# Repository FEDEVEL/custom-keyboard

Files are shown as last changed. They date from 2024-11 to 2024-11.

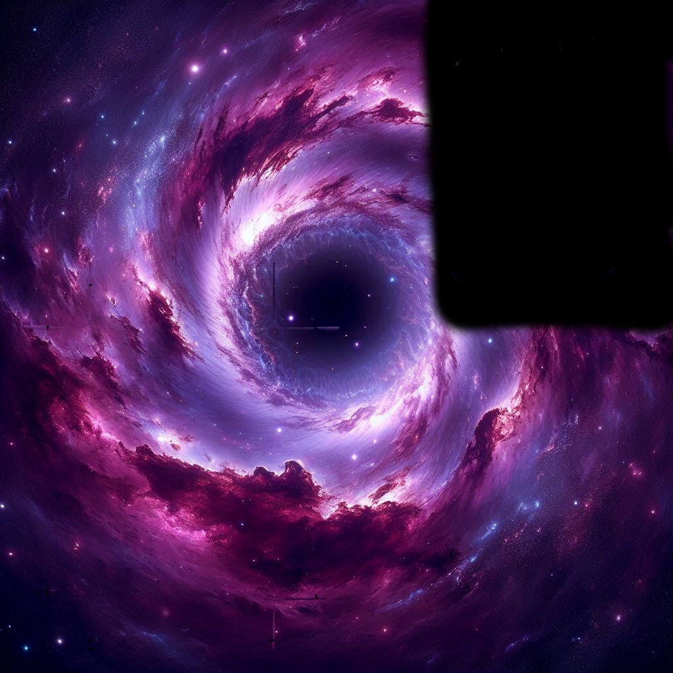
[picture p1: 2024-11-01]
Hardware/Manufacturing/Top and Bottom Box - Multicolor/bttex.png

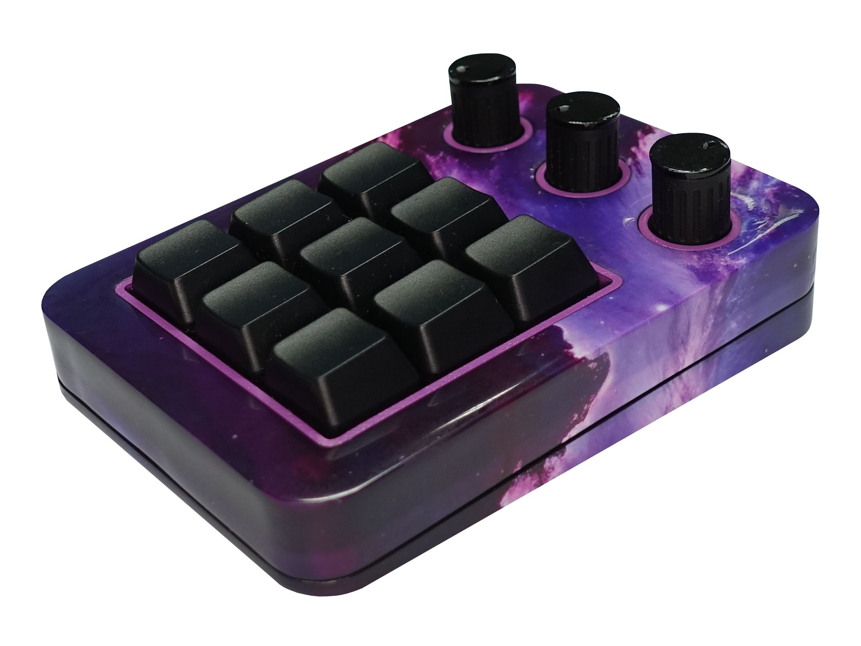
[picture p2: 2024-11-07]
Assets/keyboard.jpg

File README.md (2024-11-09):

# Custom keyboard
To design this keyboard by yourself watch my full step-by-step tutorial here: https://www.youtube.com/playlist?list=PLXvLToQzgzdftro2qK5In8p6ExsDFdpzw

Custom Keyboard Tutorial (https://www.youtube.com/watch?v=N4cLFE0FF2U)

## What is here
You will find here all the files needed to build the custom keyboard from my video tutorial.

## Other
### Have a look at the schematic and PCB layout
You can open schematic and PCB directly here: https://oshwlab.com/robertferanec/custom-keyboard
### See the 3D files
You can download 3D files also from my thingiverse here: https://www.thingiverse.com/thing:6784228 

# License
Custom Keyboard © 2025 by FEDEVEL is licensed under [Creative Commons Attribution-NonCommercial-ShareAlike 4.0 International](https://creativecommons.org/licenses/by-nc-sa/4.0/?ref=chooser-v1). For commercial use, contact me at info@fedevel.com

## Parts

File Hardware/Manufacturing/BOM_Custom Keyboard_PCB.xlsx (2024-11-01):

No. | Quantity | Comment | Designator | Footprint | Value | Manufacturer Part | Manufacturer | Supplier Part | Supplier | Layer
1 | 7 | 2.2uF | C101,C105,C106,C107,C201,C202,C207 | C0402 | 2.2uF | CL05A225MQ5NSNC | SAMSUNG(三星) | C12530 | LCSC | B
2 | 21 | 100nF | C102,C103,C104,C108,C109,C113,C114,C115,C116,C125,C126,C127,C210,C211,C212,C213,C214,C215,C216,C217,C218 | C0402 | 100nF | CL05B104KO5NNNC | SAMSUNG(三星) | C1525 | LCSC | B
3 | 4 | 1uF | C110,C111,C118,C119 | C0402 | 1uF | CL05A105KA5NQNC | SAMSUNG(三星) | C52923 | LCSC | B
4 | 1 | 47uF | C112 | C1206 | 47uF | CL31A476MPHNNNE | SAMSUNG(三星) | C96123 | LCSC | B
5 | 2 | 15pF | C123,C124 | C0402 | 15pF | CL05C150JB5NNNC | SAMSUNG(三星) | C86285 | LCSC | B
6 | 6 | 10nF | C203,C204,C205,C206,C208,C209 | C0402 | 10nF | CL05B103KB5NNNC | SAMSUNG(三星) | C15195 | LCSC | B
7 | 4 | GG0402052R542P | D101,D102,D103,D104 | D0402-BI |  | GG0402052R542P | Kyocera AVX | C1973257 | LCSC | B
8 | 12 | 1N5819WS | D201,D202,D203,D204,D205,D206,D207,D208,D209,D210,D211,D212 | SOD-323_L1.8-W1.3-LS2.5-RD |  | 1N5819WS | Hottech(合科泰) | C191023 | LCSC | B
9 | 3 | PEC12R-4120F-S0012 | ENC201,ENC202,ENC203 | SW-TH_PEC12R-4120F-S0012_1 |  | PEC12R-4120F-S0012 | BOURNS | C143801 | LCSC | T
10 | 1 | TYPE-C 16PIN 2MD(073) | J101 | USB-C-SMD_TYPE-C-6PIN-2MD-073 |  | TYPE-C 16PIN 2MD(073) | SHOU HAN(首韩) | C2765186 | LCSC | B
11 | 9 | CPG151101S11-16 | J201,J202,J203,J204,J205,J206,J207,J208,J209 | SMD_KEYBOARD-SW_1 |  | CPG151101S11-16 | Kailh(凯华) | C5156480 | LCSC | B
12 | 1 | NH-B1010RGBT-HF | LED101 | LED-ARRAY-SMD_4P-L1.0-W1.0-TR_NH-B1010RGBT_1 |  | NH-B1010RGBT-HF | 国星光电 | C2874113 | LCSC | T
13 | 1 | KT-0805G | LED102 | LED0805-R-RD |  | KT-0805G | KENTO | C2297 | LCSC | T
14 | 1 | KT-0805Y | LED103 | LED0805-R-RD |  | KT-0805Y | KENTO | C2296 | LCSC | T
15 | 9 | SK6812MINI-E | LED201,LED202,LED203,LED204,LED205,LED206,LED207,LED208,LED209 | LED-SMD_L3.2-W2.8-TR |  | SK6812MINI-E | 欧思科光电 | C5149201 | LCSC | B
16 | 4 | STANDOFF_M2.5x3.5MM | MH201,MH202,MH203,MH204 | STANDOFF_M2.5x3.5MM_RF_v1.0 |  |  | WURTH ELEKTRONIK | 3757968 | FARNELL | T
17 | 1 | 200Ω | R101 | R0402 | 200Ω | 0402WGF2000TCE | UNI-ROYAL(厚声) | C25087 | LCSC | B
18 | 1 | 100mΩ | R102 | R1206 | 100mΩ | 1206W4F100LT5E | UNI-ROYAL(厚声) | C25334 | LCSC | B
19 | 7 | 1kΩ | R103,R104,R105,R106,R107,R121,R124 | R0402 | 1kΩ | 0402WGF1001TCE | UNI-ROYAL(厚声) | C11702 | LCSC | B
20 | 7 | 27Ω | R108,R109,R110,R111,R112,R117,R125 | R0402 | 27Ω | 0402WGF270JTCE | UNI-ROYAL(厚声) | C25100 | LCSC | B
21 | 4 | 0Ω | R113,R114,R115,R116 | R0402 | 0Ω | 0402WGF0000TCE | UNI-ROYAL(厚声) | C17168 | LCSC | B
22 | 2 | 5.1kΩ | R118,R119 | R0402 | 5.1kΩ | 0402WGF5101TCE | UNI-ROYAL(厚声) | C25905 | LCSC | B
23 | 13 | 10kΩ | R123,R201,R202,R203,R204,R205,R206,R207,R208,R209,R210,R211,R212 | R0402 | 10kΩ | 0402WGF1002TCE | UNI-ROYAL(厚声) | C25744 | LCSC | B
24 | 2 | TS-1187A-B-A-B | SW101,SW102 | SW-SMD_4P-L5.1-W5.1-P3.70-LS6.5-TL-2 |  | TS-1187A-B-A-B | XKB Connectivity(中国星坤) | C318884 | LCSC | B
25 | 9 | CPG151101S21 | SW201,SW202,SW203,SW204,SW205,SW206,SW207,SW208,SW209 | KEY-TH_CPG1511F01S0X_1 |  | CPG151101S21 | Kailh(凯华) | C404351 | LCSC | T
26 | 1 | RP2040 | U101 | LQFN-56_L7.0-W7.0-P0.4-EP_1 |  | RP2040 | Raspberry Pi(树莓派) | C2040 | LCSC | B
27 | 1 | LM3940IMP-3.3/NOPB | U102 | SOT-223_L6.5-W3.5-P2.30-LS7.0-BR |  | LM3940IMP-3.3/NOPB | TI(德州仪器) | C140319 | LCSC | B
28 | 1 | SN74LV1T34DBVR | U103 | SOT-23-5_L2.9-W1.6-P0.95-LS2.8-BR |  | SN74LV1T34DBVR | TI(德州仪器) | C100024 | LCSC | B
29 | 1 | W25Q128JVSIQ | U104 | SOIC-8_L5.3-W5.3-P1.27-LS8.0-BL |  | W25Q128JVSIQ | WINBOND(华邦) | C97521 | LCSC | B
30 | 1 | ABM8-272-T3 | Y101 | CRYSTAL-SMD_4P-L3.2-W2.5-BL |  | ABM8-272-T3 | ABRACON | C20625731 | LCSC | B

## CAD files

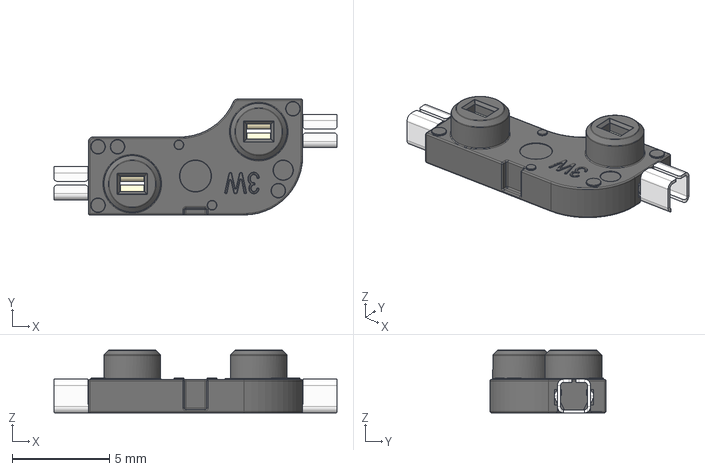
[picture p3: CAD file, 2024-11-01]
Hardware/3D models/Kailh Hotswap MX v22 RF v1_0.step
14.5 x 5.95 x 3.22 mm

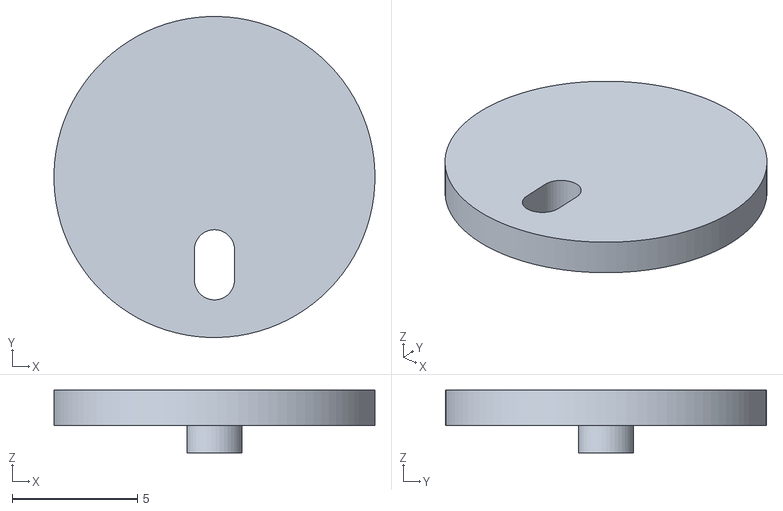
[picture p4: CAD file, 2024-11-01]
Hardware/Manufacturing/For All Boxes/knob_top_print_3x.stl
12.8 x 12.8 x 2.50

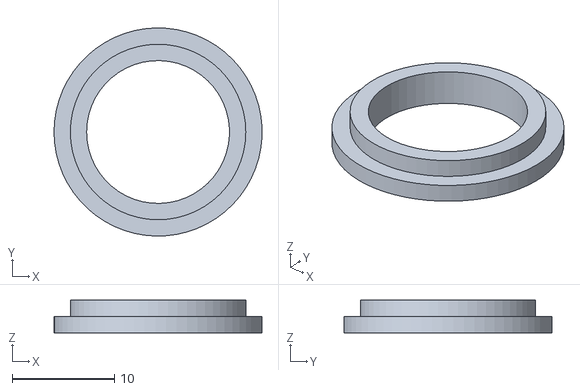
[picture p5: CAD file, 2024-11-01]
Hardware/Manufacturing/For Not Simple Box/ring_print_3x.stl
20.4 x 20.4 x 3.20

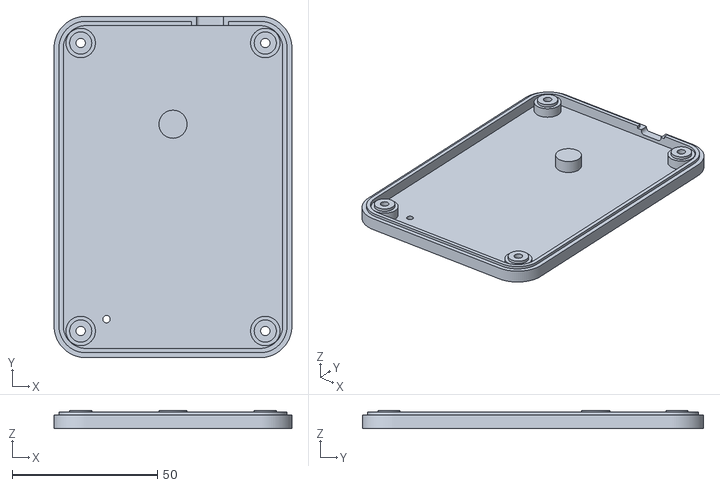
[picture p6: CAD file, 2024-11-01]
Hardware/Manufacturing/Simple Box/bottom_simple_box.stl
81.9 x 117.4 x 6.32

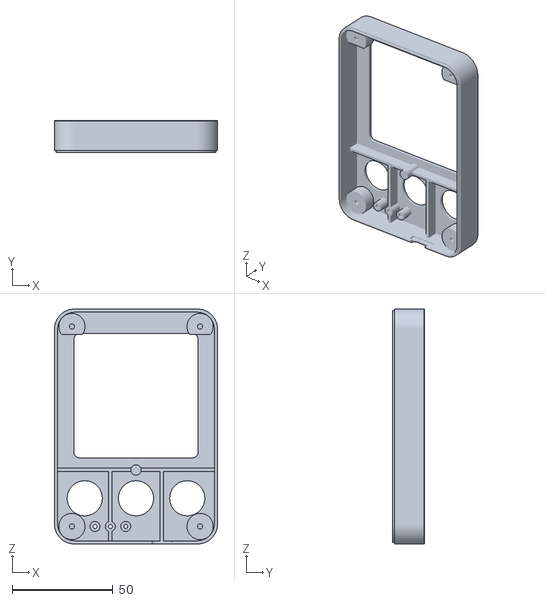
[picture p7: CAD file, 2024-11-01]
Hardware/Manufacturing/Top and Bottom Box - Multicolor/case-top.obj
80.9 x 15.7 x 116.4

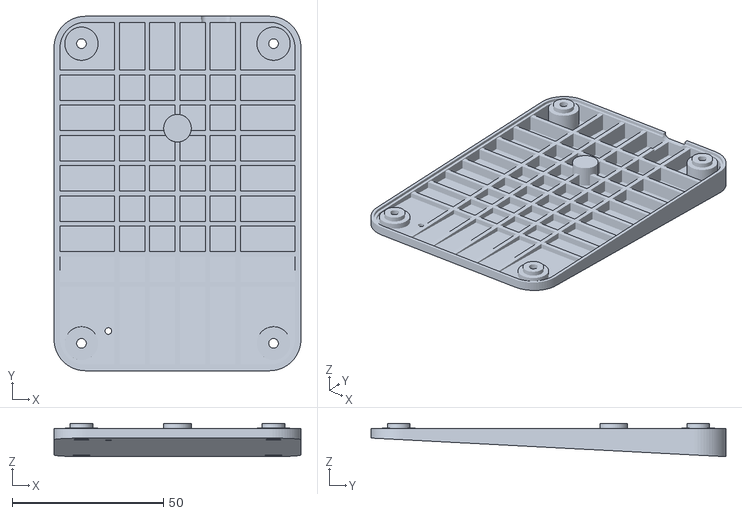
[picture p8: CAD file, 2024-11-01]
Hardware/Manufacturing/Top and Bottom Box/bottom.stl
81.7 x 117.2 x 11.0

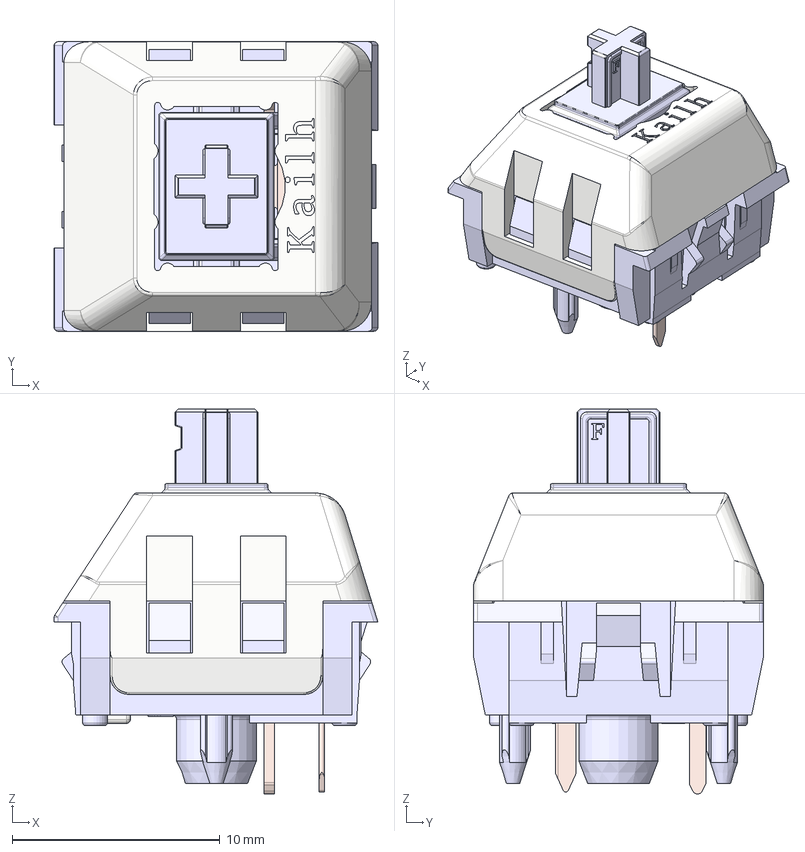
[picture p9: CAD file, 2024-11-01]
Hardware/3D models/Kailh Polia RF v1_0.step
15.6 x 14.0 x 18.5 mm
Housing
ThickContact
SpringContact
Stem
Lid

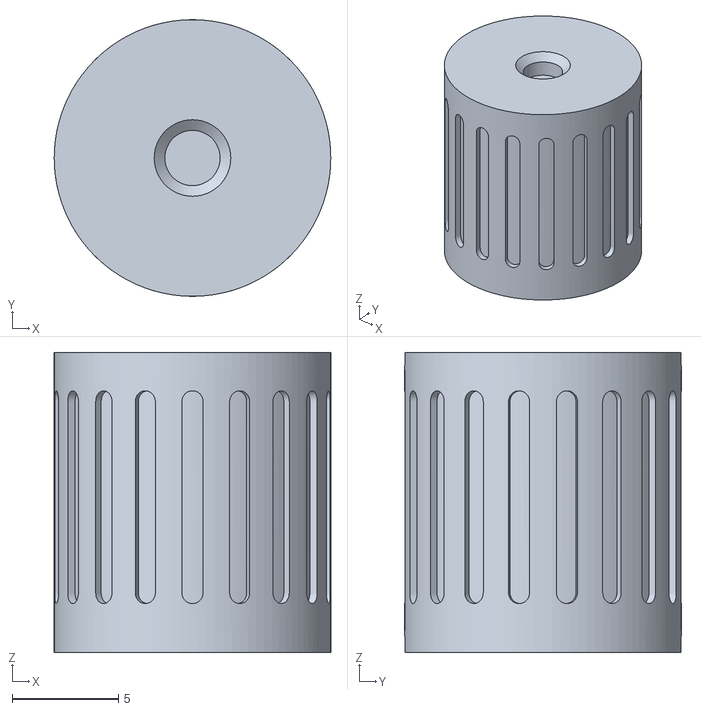
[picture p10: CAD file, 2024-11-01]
Hardware/Manufacturing/For All Boxes/knob_body_print_3x.stl
13.0 x 13.0 x 14.1

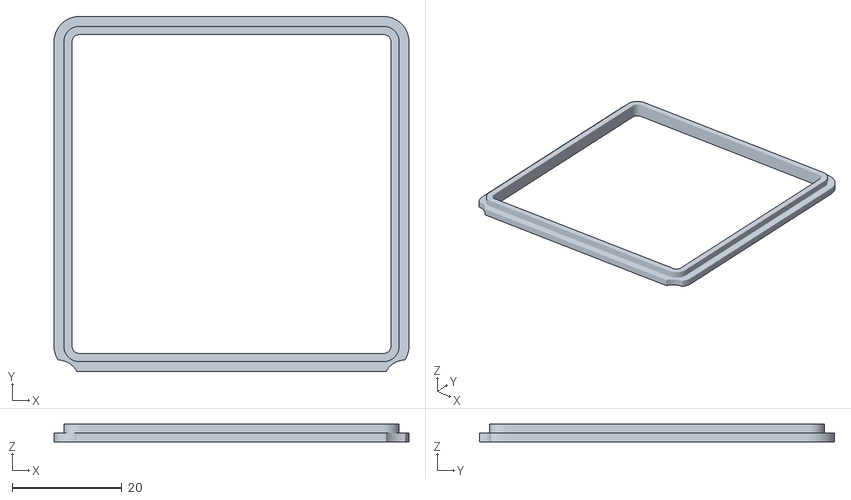
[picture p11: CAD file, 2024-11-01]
Hardware/Manufacturing/For Not Simple Box/frame.stl
64.8 x 64.8 x 3.20

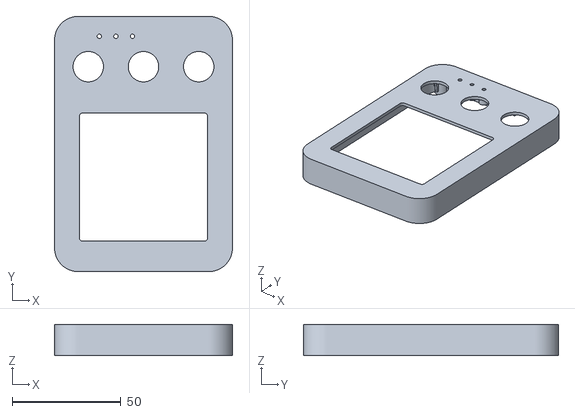
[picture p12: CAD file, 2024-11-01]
Hardware/Manufacturing/Simple Box/top_simple_box.stl
81.9 x 117.4 x 14.4

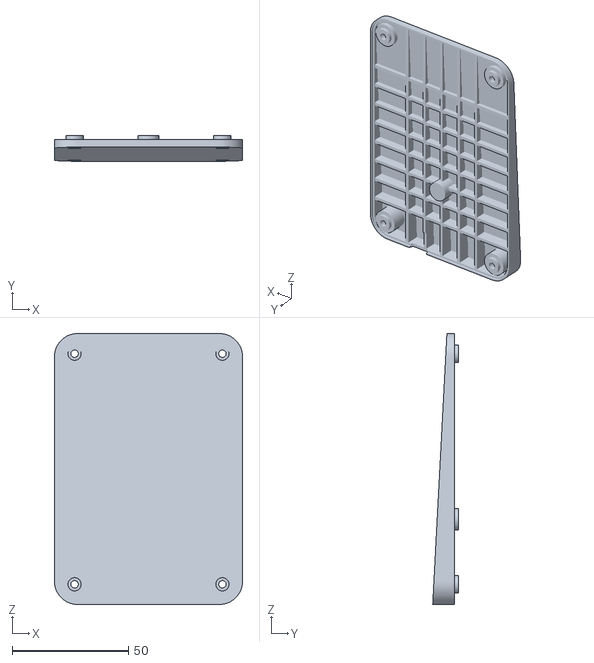
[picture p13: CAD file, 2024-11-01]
Hardware/Manufacturing/Top and Bottom Box - Multicolor/case-bottom.obj
80.9 x 11.0 x 116.4

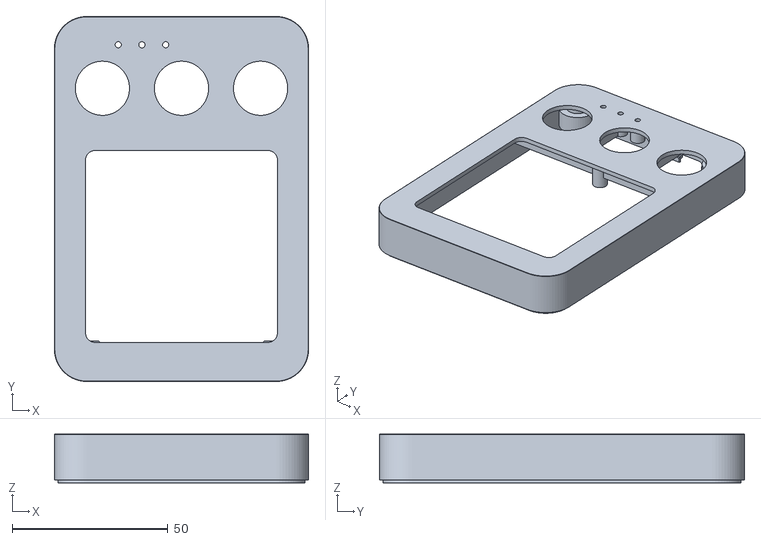
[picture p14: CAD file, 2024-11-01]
Hardware/Manufacturing/Top and Bottom Box/top.stl
81.7 x 117.2 x 15.7

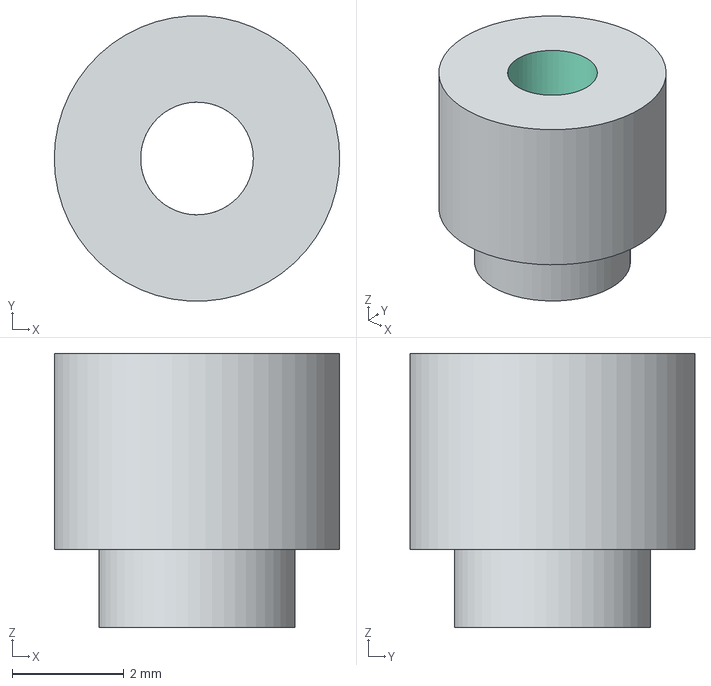
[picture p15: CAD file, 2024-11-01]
Hardware/3D models/STP_9774035151_rev1 RF v1_0.stp
5.10 x 5.09 x 4.90 mm

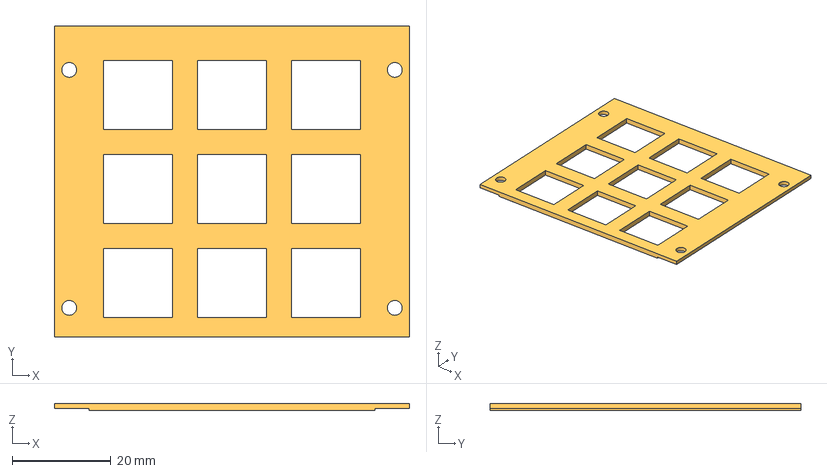
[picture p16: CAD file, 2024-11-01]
Hardware/Manufacturing/For All Boxes/plate_for_cnc.step
72.0 x 63.0 x 1.50 mm

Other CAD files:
Hardware/Manufacturing/For All Boxes/plate_for_industrial_printing_2mm.stl

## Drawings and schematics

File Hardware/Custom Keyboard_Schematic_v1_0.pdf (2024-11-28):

# Custom Keyboard (Page 1/2)

5V to 3V3 | MCU

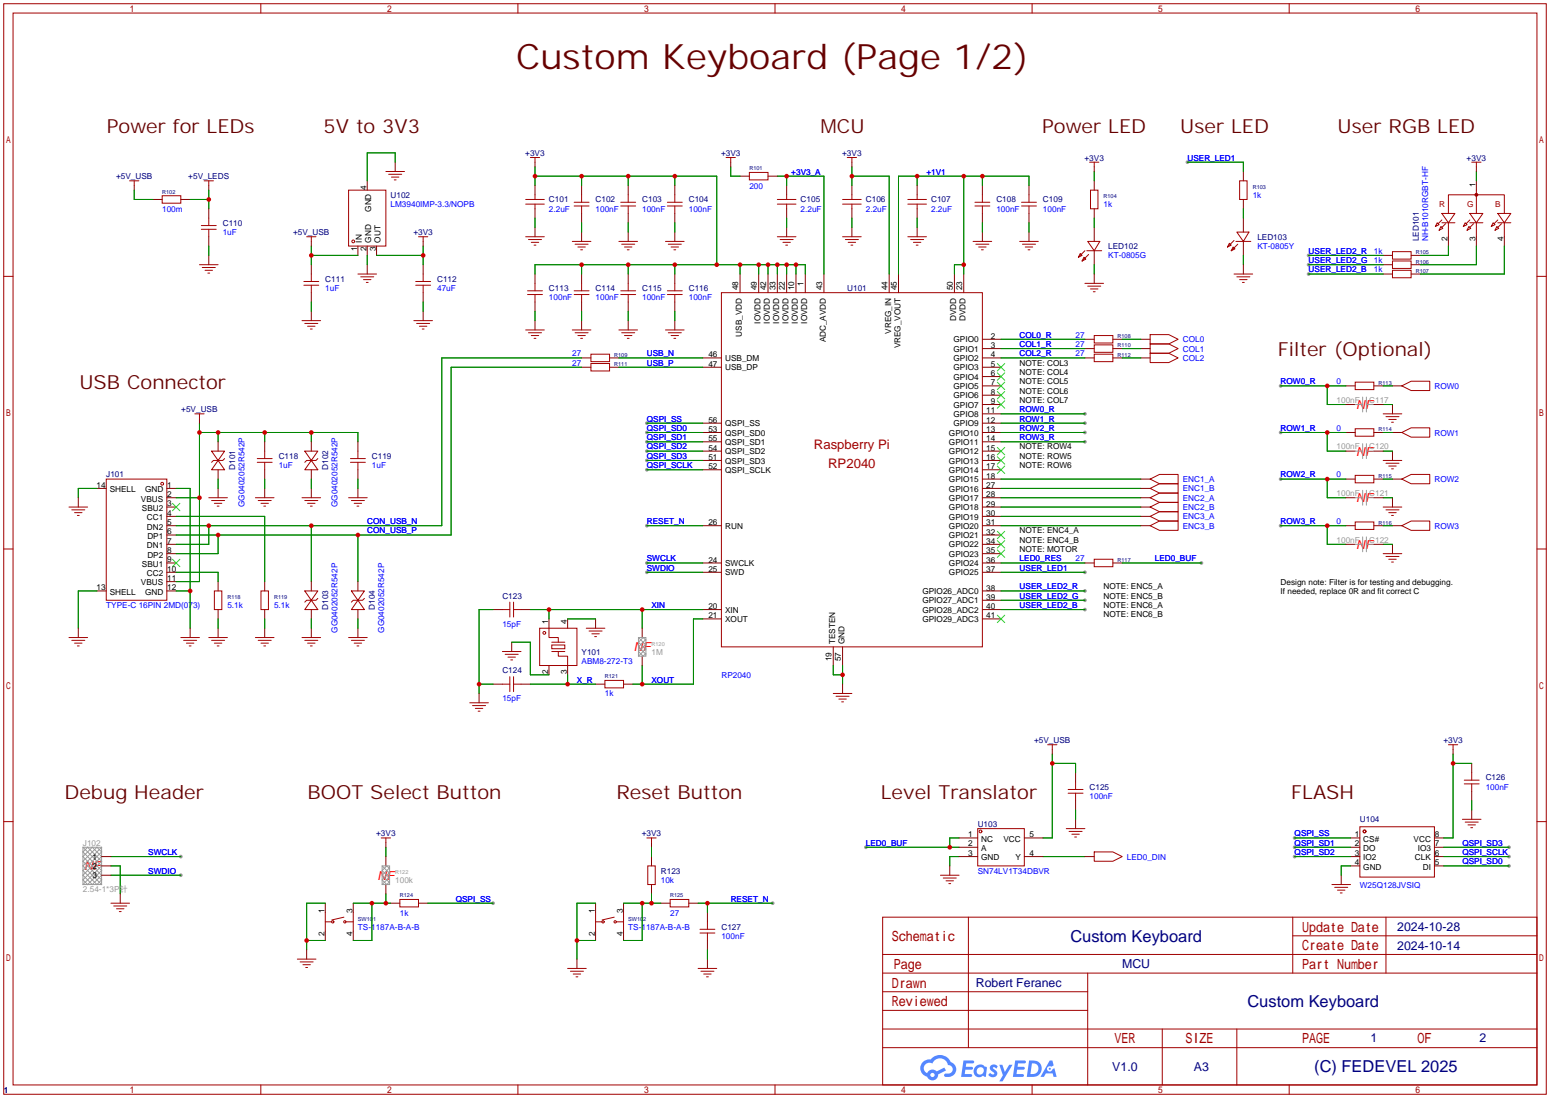
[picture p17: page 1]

Design note: Filter is for testing and debugging.
If needed, replace 0R and fit correct C

# Custom Keyboard (Page 2/2)

KEYS | ENCODER 1

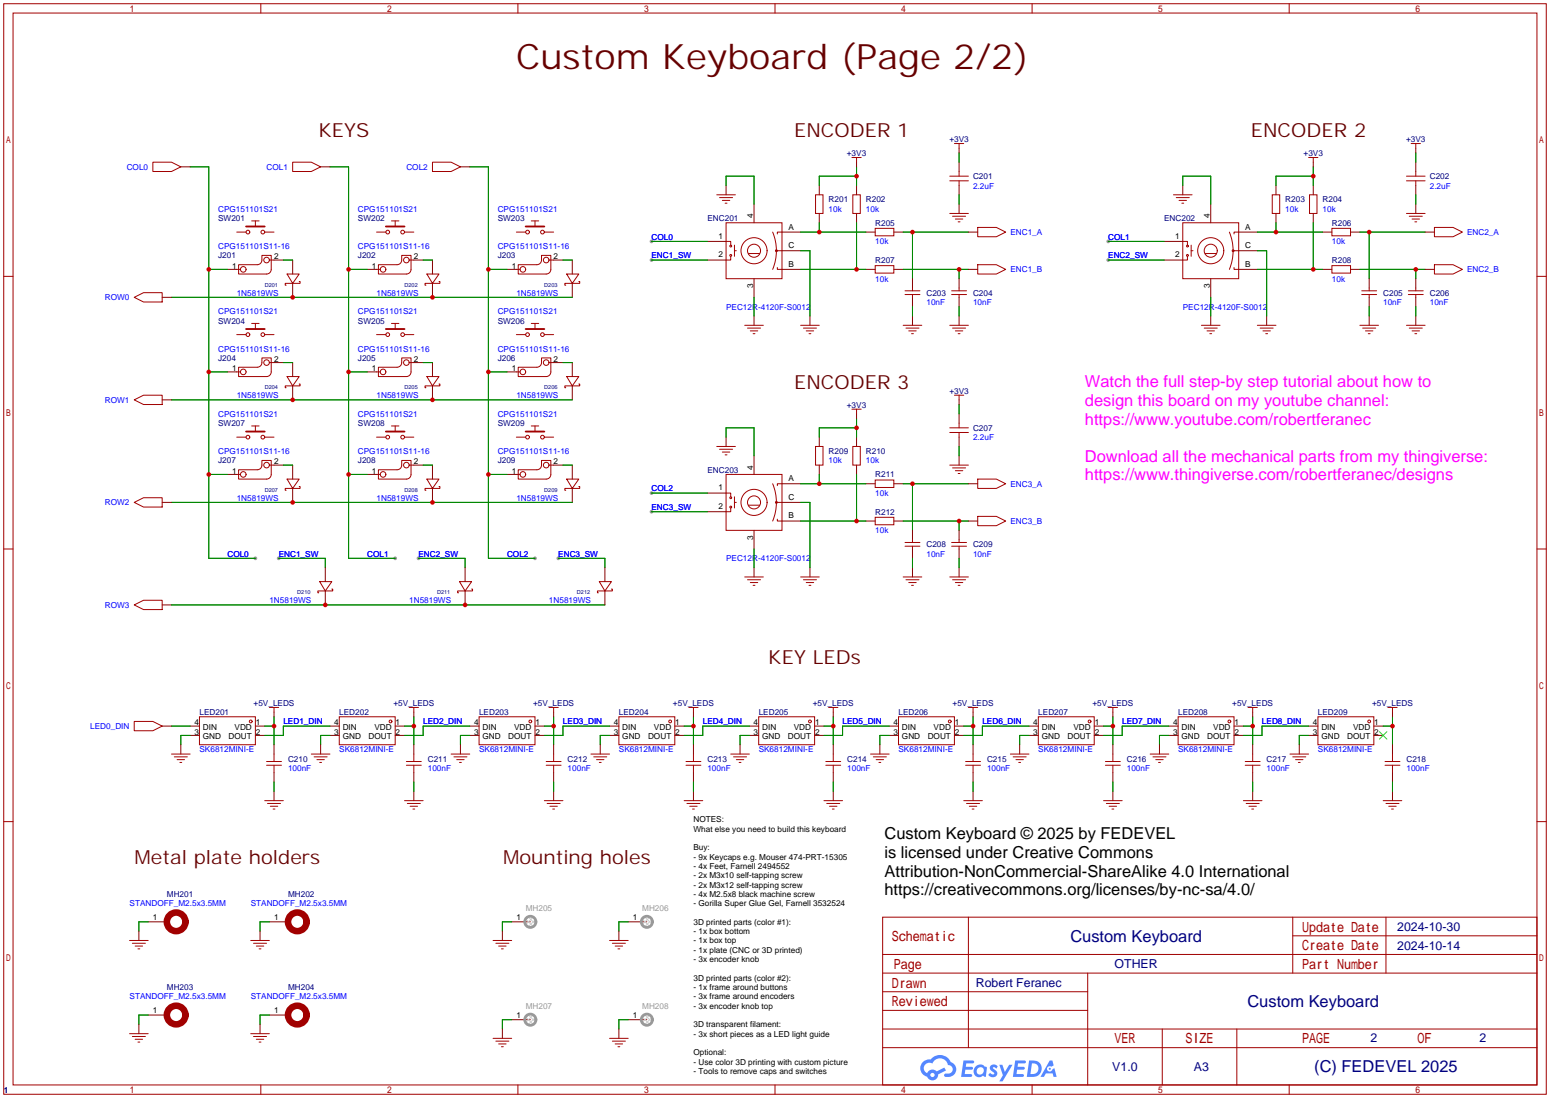
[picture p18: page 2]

Watch the full step-by step tutorial about how to
design this board on my youtube channel:
https://www.youtube.com/robertferanec
Download all the mechanical parts from my thingiverse:
https://www.thingiverse.com/robertferanec/designs

NOTES:
What else you need to build this keyboard
Buy:
- 9x Keycaps e.g. Mouser 474-PRT-15305
- 4x Feet, Farnell 2494552
- 2x M3x10 self-tapping screw
- 2x M3x12 self-tapping screw
- 4x M2.5x8 black machine screw
- Gorilla Super Glue Gel, Farnell 3532524
3D printed parts (color #1):
- 1x box bottom
- 1x box top
- 1x plate (CNC or 3D printed)
- 3x encoder knob
3D printed parts (color #2):
- 1x frame around buttons
- 3x frame around encoders
- 3x encoder knob top
3D transparent filament:
- 3x short pieces as a LED light guide
Optional:
- Use color 3D printing with custom picture
- Tools to remove caps and switches

Custom Keyboard © 2025 by FEDEVEL
is licensed under Creative Commons
Attribution-NonCommercial-ShareAlike 4.0 International
https://creativecommons.org/licenses/by-nc-sa/4.0/
